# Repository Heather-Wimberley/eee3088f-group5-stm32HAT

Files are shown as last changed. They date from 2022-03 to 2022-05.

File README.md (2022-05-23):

# EEE088F Group 5

A HAT design to be added to the STM32 microcontroller.

## Proximity and Temperature Sensing HAT

Our HAT will include a temperature and proximity sensor. These sensors will allow for our HAT to provide the device it is attached to with useful parameters of its environment. The device we will be attaching our HAT to is the STM32 Discovery Microcontroller. The scenario we would use our HAT in would be to create efficient water dispensers. The proximity sensor will be able to detect when a bottle/hand is in position to receive water and the temperature sensor will help to monitor the water’s temperature. Other scenarios our HAT could be used in include drones, cars and automatic sliding doors

## Contents
This repo contains all files needed to understand the functionality of the HAT as well as have the HAT built. A description of the folder contents can be found below:

* [CAD](https://gitlab.com/wmbhea001/eee088f-group-5/-/tree/main/CAD) - Models and designs associated with the project

* [Docs](https://gitlab.com/wmbhea001/eee088f-group-5/-/tree/main/Docs) - Documentation which may include schematics, datasheets and manuals

* [Firmware](https://gitlab.com/wmbhea001/eee088f-group-5/-/tree/main/Firmware) - Source code for the HAT's software interface. 

* [PCB](https://gitlab.com/wmbhea001/eee088f-group-5/-/tree/main/PCB) - Contains PCB schematic diagrams 

* [Production](https://gitlab.com/wmbhea001/eee088f-group-5/-/tree/main/Production) - Documents relating to cost of HAT and production of HAT

* [Simulation](https://gitlab.com/wmbhea001/eee088f-group-5/-/tree/main/PCB/Simulation) - Contains documents neccessary for the fabrication of the HAT

## Get started with Proximity and Temperature HAT

### Introduction 
In the guide below, the process of how to set-up and run the Proximity and Temperature HAT will be described. The HAT is intended to be attached to and powered by a STM32 Discovery Board and powered by an 18650 battery when the STM is not connected to an external device via USB. It is able to store data in memory and in future versions provide this data to the USB-connected device.

### What you will need
Hardware:
- STM Discovery Board
- USB mini-B
- Female Pin-Headers (ver 1)
- Male-Female Wires (ver 1)
- USB micro-B
- 18650 Battery (optional)
- 18650 Battery Holder (optional)

Software:
- STM32CubeIDE

### Setup
1.	Plug the STM discovery board into the HAT with both USBs on the same side (pin headers and wires are used in the original version to account for the footprint issue as seen below).

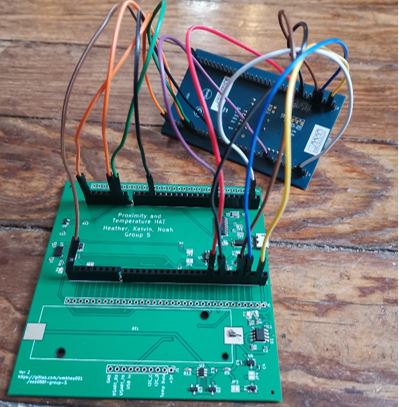
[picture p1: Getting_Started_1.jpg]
Getting_Started_1


*Figure 1: STM32F051 Discovery Board connected to Proximity and Temperature HAT (version 1 with wires)*

2.	Connect the HAT to a power source by either
- Clipping the 18650 battery holder to the connection shown below and place the battery in the holder (the lights on the discovery board should turn on)

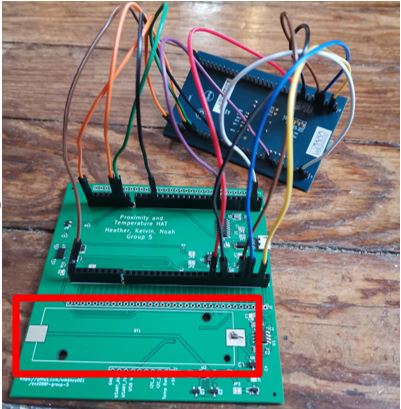
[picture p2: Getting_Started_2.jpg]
Getting_Started_2


*Figure 2: Location to plug in battery holder*

OR

- Plugging the HAT into a USB power source using the USB micro-B which will turn on the light D4

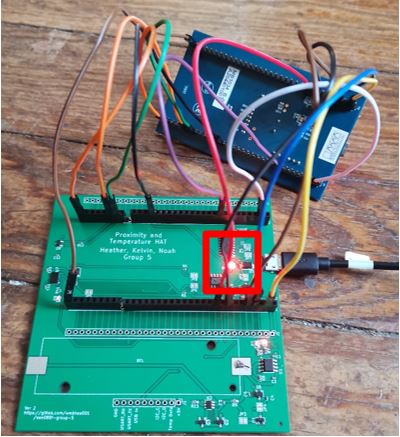
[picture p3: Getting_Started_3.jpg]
Getting_Started_3


*Figure 3: HAT powered by USB connection with USB detect light on*

3.	Plug the STM discovery board into your computer used for coding using the USB mini-B

4.	Open the firmwave files in the CubeIDE application. Add the following code to the main.c file in the section called int main(void). This serves as the main section to add code to interface with the HAT
 
```c
int main(void)
{
  Initialise(); //start all peripherals on the discovery board

  while (1)
  {
    uint32_t proximity, temp;//variables to store the proximity and temperature data
    uint8_t dataRead[32678];//array of all the data on the EEPROM
    get_sensor_data(&proximity, &temp);//measure the values at the sensors
    store_one_set(&temp, &proximity);//store the values on the EEPROM
    read_all_data(&dataRead);//read the EEPROM data into the variable 
  }
}
```

5.	Run a debug in the CubeIDE and add a watch to the dataRead variable. Stepping through the code will allow you to observe the changes in the EEPROM (future versions of the HAT will display this directly to an interface)

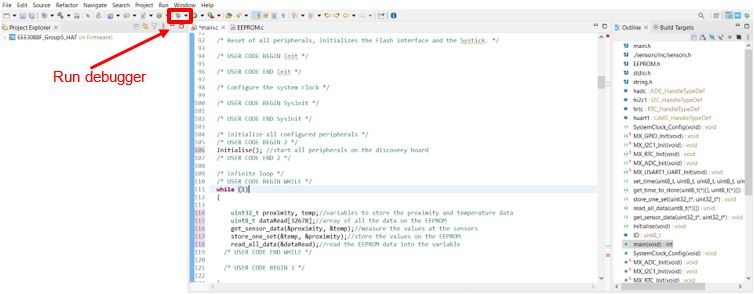
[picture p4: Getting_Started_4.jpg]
Getting_Started_4


*Figure 4: Run the debugger from the CubeIDE*

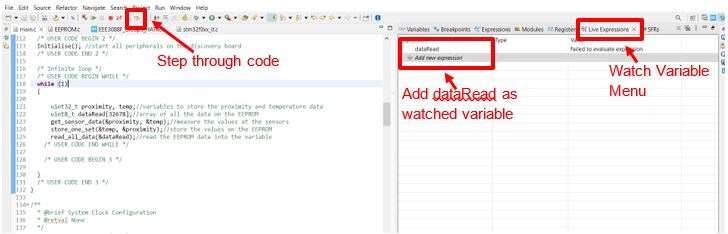
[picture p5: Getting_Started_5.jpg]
Getting_Started_5


*Figure 5: Add dataRead as a watched variable and step through the code*

Congratulations! You now have a HAT for your STM32 discovery board that can measure temperature and proximity.

## Support
Any questions concerning the project can be addressed to the project developers at wmbhea001@myuct.ac.za; ynkkel001@myuct.ac.za or; hvknoa001@myuct.ac.za

## Contributing
Please refer to [Contributing.md](https://gitlab.com/wmbhea001/eee088f-group-5/-/blob/main/CONTRIBUTING.md) for more information

## Authors and acknowledgment
Project designers are Kelvin Yankey, Heather Wimberley and Noah Havik.

## License
This project is bound by the Apache License 2.0

## Project status
Project is currently under development.

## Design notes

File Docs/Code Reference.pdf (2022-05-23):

Proximity and Temperature HAT | Group 5 | Software Documentation

# Proximity and Temperature HAT: Software Documentation

# Contents

# Overview

This document contains information on all the code that has been written and compiled as a companion to the proximity and temperature HAT that was designed. It also contains all files needed to run the HAT as intended.

# Files

### User Application Files

The basic software of the Proximity and Temperature HAT interfacing with the STM32f0 discovery board is comprised of the following files. This have been written or compiled by the engineering team.

File | Description
main.h/ .c | This file contains all of the functions written to allow a more user-friendly interface with the other files. It also initialises the STM32f0. User code can be written here to change the functioning of the board and microcontroller.
EEPROM.h/ .c | This file is a library written by controllerstech downloadable at https://github.com/controllerstech/STM32/tree/master/EEPROM_STM32.

| This library was used to simplify the user commands needed to read, write to the EEPROM and erase the EEPROM
prox.h/ .c | Contains definitions for functions used to control the proximity sensor
temp.h/ .c | Contains definitions for functions used to control the temperature sensor
types.h | Contains the definitions for types used throughout the API
sensors.h | Contains the public facing functions of the sensor api and is intended to be used by the end user

Table 1: User Application Files

### HAL files

The next files are HAL drivers needed to run the above code. The descriptions have been obtained from the HAL API documentation found at https://www.st.com/resource/en/user_manual/dm00105879-description-of-stm32f4-hal-and-ll-drivers-stmicroelectronics.pdf. (https://www.st.com/resource/en/user_manual/dm00105879-description-of-stm32f4-hal-and-ll-drivers-stmicroelectronics.pdf)

File | Description
stm32f0xx_hal_conf.h | This file allows the user to customize the HAL drivers for a specific application. It is not mandatory to modify this configuration. The application can use the default configuration without any modification.
stm32f0xx_it.h/ .c | This file contains the exceptions handler and peripherals interrupt service routine, and calls HAL_IncTick() at regular time intervals to increment a local variable (declared in stm32f4xx_hal.c) used as HAL timebase. By default, this function is called each 1ms in Systick ISR. The PPP_IRQHandler() routine must call HAL_PPP_IRQHandler() if an interrupt based process is used within the application.
stm32f0xx_hal_msp.c | This file contains the MSP initialization and de-initialization (main routine and callbacks) of the peripheral used in the user application.
system_stmf0xx.c | This file contains SystemInit() that is called at startup just after reset and before branching to the main program. It does not configure the system clock at startup (contrary to the standard library). This is to be done using the HAL APIs in the user files. It allows relocating the vector table in internal SRAM and configuring the FSMC/FMC (when available) to use the external SRAM or SDRAM mounted on the evaluation board as data memory.

Table 2: HAL Files

# Functions

### Main.c

SystemClock_Config
Function Name
void SystemClock_Config(void);

Function Description
Initializes the system clock for the STM32f0

Parameters
None

Return Values
None

MX_GPIO_Init
Function Name
static void MX_GPIO_Init(void);

Function Description
Initializes the GPIO for the STM32f0 including the pins for the USB detect (including the associated interrupt), Temperature active, Proximity active, Proximity Interrupt and discovery board LEDS.

Parameters
None

Return Values
None

MX_I2C1_Init
Function Name
static void MX_I2C1_Init(void);

Function Description
Initializes the I2C1 communication line for the STM32f0 using pins PB7 and PB8.

Parameters
None

Return Values
None

MX_RTC_Init
Function Name
static void MX_RTC_Init(void);

Function Description
Initializes the RTC (real time clock) onboard the STM32f0. Default time is 16:30:00 on 19/05/2022

Parameters
None

Return Values
None

MX_ADC_Init
Function Name
static void MX_ADC_Init(void);

Function Description
Initializes the ADC for the STM32f0 to receive data from the temperature sensor

Parameters
None

Return Values
None

set_time
Function Name
void set_time(uint8_t hour,uint8_t minute, uint8_t second, uint8_t Month, uint8_t Date, uint8_t Year);

Function Description
Sets the time of the real time clock to a user specified time

Parameters
Hour: user defined hour
minute: user defined minute
second: user defined second
Month: user defined month. Can use RTC definitions eg. RTC_MONTH_MAY
Date: user defined date
Year: user difined year. Needs to be less then 255 so store year-2000 and add the 2000 when displaying later

Return Values
None

get_time_to_store
Function Name
void get_time_to_store(uint8_t (*time)[3],uint8_t (*date)[3]);

Function Description
Retrives the current time and date from the RTC and stores it in 2 arrays of length 3 and size one byte. One array has time and the other has the date

Parameters
time: pointer to user defined array of 3 variables that will store current time
date: pointer to user defined array of 3 variables that will store current time

Return Values
None

store_one_set
Function Name
void store_one_set(uint32_t *temp, uint32_t *proximity);

Function Description
Stores one set of data in the EEPROM which includes the ID of that set, the temperature data, proximity data and the time from the RTC.

Parameters
temp: pointer to user defined uint32 containing the temperature
proximity: pointer to user defined uint32 containing the proximity

Return Values
None

read_all_data
Function Name
void read_all_data (uint8_t (*dataRead)[32678]);

Function Description
Reads all of the data currently stored on the EEPROM and stores it in an array

Parameters
dataRead: pointer to user defined array that will store the EEPROM data

Return Values
None

get_sensor_data
Function Name
void get_sensor_data (uint32_t *proximity,uint32_t *temp);

Function Description
Stores the data currently received from the 2 sensors in user defined variables

Parameters
proximity: pointer to user defined byte to contain proximity
temp: pointer to user defined byte to contain proximity

Return Values
None

get_sensor_data
Function Name
void Intialise(void);

Function Description
Initialises all of the STM32 functions as well as starting the sensors. It contains all previously mentioned initialisation functions

Parameters
None

Return Values
None

HAL_GPIO_EXTI_Callback
Function Name
void HAL_GPIO_EXTI_Callback(uint16_t GPIO_Pin);

Function Description
Defines the action taken of the USB detect interrupt

Parameters
GPIO_Pin: Pin connected to the interrupt

Return Values
None

Global Variables
uint8_t ID – stores the current value of the ID that is used to store values in the EEPROM

### EEPROM.c

All of the following references and information have been copied from the original library

EEPROM_Write
Function Name
void EEPROM_Write (uint16_t page, uint16_t offset, uint8_t *data, uint16_t size)

Function Description
write the data to the EEPROM

Parameters
page: the number of the start page. Range from 0 to PAGE_NUM-1 offset: the start byte offset in the page. Range from 0 to PAGE_SIZE-1 data: the pointer to the data to write in bytes
size: the size of the data

Return Values
None

EEPROM_Write_NUM
Function Name
void EEPROM_Write_NUM (uint16_t page, uint16_t offset, float data)

Function Description
Write the Float/Integer values to the EEPROM

Parameters
page: the number of the start page. Range from 0 to PAGE_NUM-1 offset: the start byte offset in the page. Range from 0 to PAGE_SIZE-1 data: the float/integer value that you want to write

Return Values
None

EEPROM_Read_NUM
Function Name
float EEPROM_Read_NUM (uint16_t page, uint16_t offset)

Function Description
Reads the single Float/Integer values from the EEPROM

Parameters
page: the number of the start page. Range from 0 to PAGE_NUM-1 offset: the start byte offset in the page. Range from 0 to PAGE_SIZE-1

Return Values
the float/integer value

EEPROM_Read
Function Name
void EEPROM_Read (uint16_t page, uint16_t offset, uint8_t *data, uint16_t size)

Function Description
READ the data from the EEPROM

Parameters
page: the number of the start page. Range from 0 to PAGE_NUM-1 offset: the start byte offset in the page. Range from 0 to PAGE_SIZE-1 data: the pointer to the data to write in bytes
size: the size of the data

Return Values
None

EEPROM_PageErase
Function Name
float EEPROM_Read_NUM (uint16_t page, uint16_t offset)

Function Description
Erase a page in the EEPROM Memory. In order to erase multiple pages, just use this function in the for loop

Parameters
page: the number of the pages to erase

Return Values
None

### Sensors.h

The following list of functions comprise the public facing functions of the sensor api and is intended to be used by the end user

Sensors_Start
Function Name
SensorErrorType Sensors_Start(ADC_HandleTypeDef *hadc, I2C_HandleTypeDef* i2cHandler)

Function Description
Initialize the Sensors to start the data collection process
Parameters
- hadc - the handler of the adc configured by the user. Instructions about specific ports can be found in the readme
- i2cHandler - the handler of the i2c configuration defined by the user.

Return Values
SensorErrorType – Indicating the result of the operation

Sensors_Stop
Function Name
SensorErrorType Sensors_Stop(void) Function Description
Places both sensors in a standby state Parameters
N/A

Return Values
SensorErrorType – Indicating the result of the operation

Sensors_GetMeasurement
Function Name
SensorErrorType Sensors_GetMeasurement(struct SensorData *out, int maxTime) Function Description
Obtains all measurements and stores it in a pointer to sensor data

Parameters
- out - a pointer to the struct{SensorData} in which the results from measurements will be stored. End user is responsible for creating and managing the struct
- maxTime – the maximum time the operation should take, if this time is exceeded, the function will abort with an error

Return Values
SensorErrorType – Indicating the result of the operation

### Types.h

Contains the definitions for types used throughout the API

SensorData
Definition
struct SensorData {
float temp;
int32_t prox;
};

Description
This struct will hold a result from a polling measurement operation.

SensorErrorType
Definition
typedef enum SensorErrorType;

Description
An enum holding the result from various operations in the api. Below are the enum fields as well as their descriptions
- OK – The function was successful
- PROX_CALIBRATION_ERROR – The proximity sensor could not calibrate itself and thus could not start
- PROX_INIT_ERROR – The proximity sensor could not start
- PROX_MEASURE_ERROR – There was an error while getting a measurement
- PROX_NOT_RESPONDING – The proximity sensor did not respond when prompted for a result

The following section describes private definitions which should not be used by the end user

### Prox.h

Contains definitions for functions used to control the proximity sensor

ProximitySensor_Start
Function Name
SensorErrorType ProximitySensor_Start(I2C_HandleTypeDef* i2cHandler) Function Description
Starts the proximity sensor
Parameters
- i2cHandler - the handler of the i2c configuration defined by the user.

Return Values
SensorErrorType – Indicating the result of the operation

EnsureHandlersValid
Function Name
void EnsureHandlersValid(void)
Function Description
Internal function to ensure that the various handlers the api uses are still valid

Parameters
N/A

Return Values
N/A

ProximitySensor_GetSingleShotMeasurement
Function Name
SensorErrorType ProximitySensor_GetSingleShotMeasurement(int32_t* result) Function Description
Gets a distance measurement once at a time

Parameters
- result - A pointer to the integer variable holding the result of the operation in millimetres

Return Values
SensorErrorType – Indicating the result of the operation

ProximitySensor_Stop
Function Name
SensorErrorType ProximitySensor_Stop(void) Function Description
Places the proximity sensor in standby mode

Parameters
N/A

Return Values
SensorErrorType – Indicating the result of the operation

ProximitySensor_IsReady
Function Name
SensorErrorType ProximitySensor_IsReady(void) Function Description
Checks whether the proximity sensor is ready and responding

Parameters
N/A

Return Values
SensorErrorType – Indicating the result of the operation

Interrupt based functions for use if required

ProximitySensor_Start_IT
Function Name
SensorErrorType ProximitySensor_Start_IT(I2C_HandleTypeDef* i2cHandler, int freq) Function Description
Starts the proximity sensor in interrupt mode. User is responsible for setting up the GPIO interrupt in hardware

Parameters
- i2cHandler - the handler of the i2c configuration defined by the user.
- Freq – The frequency at which interrupts will occur

Return Values
SensorErrorType – Indicating the result of the operation

ProximitySensor_OnInterruptStarted
Function Name
SensorErrorType ProximitySensor_OnInterruptStarted(void) Function Description
Function to be called once the interrupt detection has been set up

Parameters
N/A

Return Values
SensorErrorType – Indicating the result of the operation

ProximitySensor_OnInterruptDetected
Function Name
SensorErrorType ProximitySensor_OnInterruptDetected(int32_t* result) Function Description
Called when the interrupt fires. Will output the measurement results

Parameters
- result - A pointer to the integer variable holding the result of the operation in millimetres

Return Values
SensorErrorType – Indicating the result of the operation

### Temp.h

Contains definitions for functions used to control the temperature sensor

TempSensor_Start
Function Name
SensorErrorType TempSensor_Start(ADC_HandleTypeDef *hadc) Function Description
Starts the temperature sensor

Parameters
- hadc - the handler of the adc configured by the user. Instructions about specific ports can be found in the readme

Return Values
SensorErrorType – Indicating the result of the operation

TempSensor_GetMeasurement
Function Name
SensorErrorType TempSensor_GetMeasurement(int maxTime, float* result) Function Description
Get the current measurement from the temperature sensor

Parameters
- result - is a pointer to a double which will hold the result
- maxTime - is the maximum amount of time you can wait before a result needs to be returned. Can be dictated by the sampling rate
Return Values
SensorErrorType – Indicating the result of the operation

TempSensor_HasStarted
Function Name
SensorErrorType TempSensor_HasStarted(void) Function Description
Checks if the temperature has started

Parameters
N/A

Return Values
SensorErrorType – Indicating the result of the operation

TempSensor_Stop
Function Name
SensorErrorType TempSensor_Stop(void) Function Description
Stop the temperature sensor

Parameters
N/A

Return Values
SensorErrorType – Indicating the result of the operation

The following files are part of source code taken from the VL6180 Api and thus, documentation can be found at the STMicroelectronics website

- vl6180_api.h/ .c
- vl6180_cfg.h
- vl6180_def.h

- vl6180_i2c.h/ .c
- vl6180_platform.h/ .c

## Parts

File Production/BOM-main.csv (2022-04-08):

Comment | Designator | Footprint | LCSC
CH340G | U3 | SOIC-16_3.9x9.9mm_P1.27mm | C14267
AO3401A | Q1 | SOT-23 | C15127
10nF | C7 | C_0402_1005Metric | C15195
100nF | C3,C9 | C_0402_1005Metric | C1525
4.7nF | C11 | C_0402_1005Metric | C1538
10uF | C1,C2 | C_0402_1005Metric | C15525
33pF | C6,C8 | C_0402_1005Metric | C1562
TP4056 | U1 | ESOP-8_L4.9-W3.9-P1.27-LS6.0-BL-EP | C16581
1k | R13,R3,R7 | R_0603_1608Metric | C21190
1.2k | R8 | R_0603_1608Metric | C22765
100 | R1,R9 | R_0603_1608Metric | C22775
RLED | D4,D6,D9 | LED_0603_1608Metric | C2286
YLED | D2 | LED_0805_2012Metric | C2296
150 | R4 | R_0402_1005Metric | C25082
330 | R10,R12 | R_0402_1005Metric | C25104
10k | R11,R5,R6 | R_0402_1005Metric | C25744
VL6180XV0NR_1 | U7 | LGA-12_L4.8-W2.8-P0.75-BL | C2655167
BZT52C3V0 | D8 | D_SOD-123 | C266562
100nF | C10 | C_0402_1005Metric | C307331
USB_Micro_B | U4 | C404969_Micro_USB | C404969
BAT54S | D1 | D_SOT-23_ANK | C408389
MCP9700T-ETT | U8 | SOT-23 | C42288
0.4 | R2 | R_0805_2012Metric | C52548
1uF | C12,C4,C5 | C_0402_1005Metric | C52923
XC6206P332MR | U6 | SOT-23 | C5446
AT24C256C-SSHL-T | U5 | SOIC-8_L4.9-W3.9-P1.27-LS6.0-BL | C6482
ZMM5V1-M | D3 | LL-34_L3.5-W1.5-RD | C8061
FS312F-G | U2 | SOT-23-6 | C82736
2N7002 | Q2,Q3 | SOT-23 | C8545
12MHz Crystal | X1 | OSC-SMD_4P-L3.2-W2.5-BL | C9002
DIODE | D5 | DO-214AC_L4.3-W2.7-LS5.3-RD | C95872

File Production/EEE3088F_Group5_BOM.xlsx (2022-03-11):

Source: | D:\UCT 2022\EEE3088F Design Principles\Task\Git\eee088f-group-5\PCB\main\main.kicad_sch
Date: |  | 2022-03-11 18:34
Tool: | Eeschema (6.0.2)
Item | Qty | Reference(s) | Value | LibPart | JLC Part # | Price ($) | Total for components | Total Cost
1 | 1 | BT1 | 5V | 18650 | - | - | -
2 | 2 | C1,C6 | 0.1uF | Device:C | C1525 | 0.0011 | 0.0022 | 7.7399
3 | 1 | C2 | 22uF | Device:C | C59461 | 0.0098 | 0.0098
4 | 1 | C3 | 300pF | Device:C | C1534 | 0.0017 | 0.0017
5 | 2 | C4, C5 | 33p | Device:C | C1562 | 0.0012 | 0.0024
7 | 1 | C7 | 100n | Device:C_Polarized | C307331 | 0.0065 | 0.0065
8 | 1 | C8 | 4.7n | Device:C_Polarized | C1538 | 0.0011 | 0.0011
9 | 2 | D1, D2 | 30V 1V@100mA 200mA | BAT54S | C408389 | 0.0148 | 0.0296
10 | 1 | D3 | 1A 5μA@1kV 1kV 1.1V@1A | 1N4007 | C106903 | 0.0189 | 0.0189
11 | 1 | D4 | 2μA@1V 85Ω Single 3.1V~3.5V 500mW 3.3V | ZMM3V3-M | C8056 | 0.0188 | 0.0188
13 | 1 | D6 | 100nA@1V 35Ω Single 4.8V~5.4V 500mW 5.1V | ZMM5V1-M | C8061 | 0.0182 | 0.0182
14 | 4 | D5, D7, D9, D10 | LED | Device:LED | C2286 | 0.0032 | 0.0128
15 | 1 | D8 | BZT52C3V0 | Diode:BZT52Bxx | C266562 | 0.0136 | 0.0136
16 | 2 | J1, J4 | Conn_01x33_Female | Connector:Conn_01x33_Female
17 | 2 | J2, J3 | Conn_01x33_Female | Connector:Conn_01x33_Female
18 | 1 | J5 | Conn_01x03_Female | Connector:Conn_01x03_Female
19 | 6 | JP1, JP2, JP3, JP4, JP5, JP6 | SolderJumper_2_Bridged | Jumper:SolderJumper_2_Bridged
20 | 6 | JP7, JP8, JP9, JP10, JP11, JP12 | SolderJumper_2_Bridged | Jumper:SolderJumper_2_Bridged
21 | 2 | M1 | 20V 2.3A 350mW 112mΩ@4.5V,2.8A 1V@250μA | CJ2301 | C8547 | 0.0447 | 0.0894
22 | 2 | Q1 | FDS6690A | Symbol_EEE3088F:FDS6690A | C87667 | 0.7380 | 1.476
23 | 1 | R 1 | 2M | Device:R | C25744 | 0.0007 | 0.0007
24 | 1 | R 2 | 806K | Device:R | C375495 | 0.0007 | 0.0007
25 | 1 | R 3 | 130 | Device:R | C25744 | 0.0007 | 0.0007
26 | 1 | R 4 | 27 | Device:R | C25190 | 0.0013 | 0.0013
27 | 2 | R 5 | 1M | Device:R | C26083 | 0.0007 | 0.0014
28 | 1 | R 6 | 1k | Device:R | C11702 | 0.0008 | 0.0008
29 | 1 | R 7 | 12 | Device:R | C880162 | 0.0111 | 0.0111
30 | 1 | R 8 | 82 | Device:R | C23255 | 0.0014 | 0.0014
31 | 4 | R9, R10, R13, R16 | 10k | Device:R | C25744 | 0.0007 | 0.0028
32 | 3 | R11, R12, R14 | 330 | Device:R | C25104 | 0.0007 | 0.0021
34 | 1 | R 15 | 220 | Device:R | C25091 | 0.0007 | 0.0007
35 | 1 | RV1 | 50K | Device:R_Potentiometer | C145161 | 0.0860 | 0.086
36 | 1 | U1 | 100mA 600mV@(100mA) Fixed 3.3V~3.3V Positive 1 30V | LP2951-33DR | C109381 | 0.5769 | 0.5769
37 | 1 | U2 | LM324 | 0.4 V/us 4 1.3MHz 3V ~ 32V, ±1.5V ~ 16V 1.5mA | C71035 | 0.1561 | 0.1561
38 | 1 | U3 | CH340G | Interface_USB:CH340G | C14267 | 0.5856 | 0.5856
39 | 1 | U4 | USB_Micro_B | Symbol_EEE3088F:USB_Micro_B_Female_Connector | C319160 | 0.0673 | 0.0673
40 | 1 | U5 | AT24C256C-SSHL-T | Symbol_EEE3088F:AT24C256C-SSHL-T | C6482 | 1.5556 | 1.5556
41 | 1 | U6 | VL6180XV0NR_1 | EEE3088Components:VL6180XV0NR_1 | C2655167 | 2.1412 | 2.1412
42 | 1 | U7 | MCP9700T-ETT | Sensor_Temperature:MCP9700T-ETT | C42288 | 0.7397 | 0.7397
43 | 1 | X1 | 12MHz Crystal | Symbol_EEE3088F:12MHz_SMD_Crystal | C9002 | 0.1054 | 0.1054
44 | 1 | R15 | 47k | Device:R | C25792 | 0.0007 | 0.0007
45 | 1 | R16 | 150k | Device:R | C25755 | 0.0007 | 0.0007
 |  |  |  |  |  |  | 7.7385

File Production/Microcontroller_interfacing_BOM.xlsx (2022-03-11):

Option No | Type | Part | JLCPCB Part # | Cost | Basic/Extended
USB Interfacing
1 | USB serial interface | Transceiver 2Mbps USB 2.0 SOP-16_150mil USB ICs ROHS | C14267 | $0.6029 | E
2 | FTDI | LQFP-48_7x7x05P USB ICs ROHS | C51997 (https://lcsc.com/product-detail/USB-ICs_FTDI-FT232HL-REEL_C51997.html) | $4.8695 | E
3 | FTDI (alt) | Transceiver 12Mbps USB 2.0 LQFP-48_7x7x05P USB ICs ROHS | C111668 | $2.718 | E
4 | FTDI (alt) | Transceiver 1Mbps USB 1/1 QFN-28_5x5x05P USB ICs ROHS | C6568 | $3.7227 | B
USB Connector
1 | USB Micro B | USB 2.0 1 5 Female Micro-B SMD USB Connectors ROHS | C319160 | $0.0673 | E
2 | USB Micro B (alt) | 1A USB 2.0 1 5 Female Micro-B SMD USB Connectors ROHS | C10418 | $0.0749 | E
EEPROM
1 | EEPROM | 1.7V ~ 5.5V I2C 256Kb (32K x 8) SOIC-8_150mil EEPROM ROHS | C6482 | $1.6371 | B
Crystal
1 | 12Mhz Crystal | 12MHz SMD Crystal Resonator 20pF ±10ppm ±30ppm -40℃~+85℃ SMD3225-4P Crystals ROHS | C9002 | $0.1054 | B
Total anticipated |  |  |  | ±$2.4127
 |  |  |  | Above is using first option
 | Not accounted for are resistors, capacitors and diodes which are cheap
 |  |  |  |  |  | Quantity
 | Red LED | Red 615~630nm 1.9~2.2V 0603 Light Emitting Diodes (LED) RoHS | C2286 | $0.0032 | B | 1
 | 75 ohm | ±1% 1/10W Thick Film Resistors 75V ±100ppm/℃ -55℃~+155℃ 82Ω 0603 Chip Resistor - Surface Mount ROHS | C23255 | $0.0014 | B | 1
 | 10k ohm | ±1% 1/16W Thick Film Resistors 50V ±100ppm/℃ -55℃~+155℃ 10kΩ 0402 Chip Resistor - Surface Mount ROHS | C25744 | $0.0007 | B | 2
 | 33pF | 50V 33pF C0G ±5% 0402 Multilayer Ceramic Capacitors MLCC - SMD/SMT ROHS | C1562 | $0.0012 | B | 2
 | 0.1uF | 16V 100nF X7R ±10% 0402 Multilayer Ceramic Capacitors MLCC - SMD/SMT ROHS | C1525 | $0.0011 | B | 1

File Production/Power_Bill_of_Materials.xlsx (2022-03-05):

Part | JLC PCB | Cost
100mA 600mV@(100mA) Fixed 3.3V~3.3V Positive 1 30V SOIC-8_150mil Linear Voltage Regulators (LDO) ROHS | C109381 | $0,53
50V 130MA 225MW 10Ω@5V,100MA 2V@250ΜA P CHANNEL SOT-23(SOT-23-3) MOSFETS ROHS | LBSS84LT1G | $0,03
0.6 V/US 2 1MHZ 3V ~ 32V, ±1.5V ~ 16V 1.5MA GENERAL PURPOSE SOIC-8_150MIL OPERATIONAL AMPLIFIER ROHS | LM358DR2G | $0.14
 | Total | ± $0.70
Resistors, capacitors and diodes not included as they are cheap, basic parts

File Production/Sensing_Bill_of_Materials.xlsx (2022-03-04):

Name | Reference | Part Number | JLC Part Number | Datasheet | Value | Cost | Quantity | Subtotal
Temperature Sensor | U1 | MCP9700T-E/TT | C42288 | https://datasheet.lcsc.com/lcsc/1809192127_Microchip-Tech-MCP9700T-E-TT_C42288.pdf | N/A | 0.8315 | 1 | 0.8315
Capacitor | C1 |  |  |  | 100n | 0 | 1 | 0
Capacitor | C2 | N/A | N/A | N/A | 4.7n | 0 | 1 | 0
 | D1 |  |  |  |  | 0 | 1 | 0
 | D2 |  |  |  |  | 0 | 1 | 0
 | D3 |  |  |  |  | 0 |  | 0
BJT Transistor | Q1 | N/A | N/A | N/A | N/A | 0 | 1 | 0
 | R1 |  |  |  |  | 0 | 1 | 0
 | R2 |  |  |  |  | 0 | 1 | 0
 | R3 |  |  |  |  | 0 | 1 | 0
 | R4 |  |  |  |  | 0 | 1 | 0
 | R5 |  |  |  |  | 0 | 1 | 0
 | R6 |  |  |  |  | 0 | 1 | 0
Proximity Sensor | U2 | VL6180XV0NR_1 | C2655167 | https://datasheet.lcsc.com/lcsc/2106080034_STMicroelectronics-VL6180V1NR-1_C2655167.pdf | N/A | 2.23 | 1 | 2.23
 |  |  |  |  |  |  |  | Total
 |  |  |  |  |  |  |  | 3.0615

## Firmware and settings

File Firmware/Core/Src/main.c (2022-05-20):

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
/* Includes ------------------------------------------------------------------*/
#include "main.h"

/* USER CODE BEGIN Includes */
#include "./sensors/inc/sensors.h"
#include "EEPROM.h"
#include <stdio.h>
#include "string.h"
/* USER CODE END Includes */

ADC_HandleTypeDef hadc;

I2C_HandleTypeDef hi2c1;

RTC_HandleTypeDef hrtc;

void SystemClock_Config(void);
static void MX_GPIO_Init(void);
static void MX_I2C1_Init(void);
static void MX_RTC_Init(void);
static void MX_ADC_Init(void);
/* USER CODE BEGIN PFP */
void set_time(uint8_t hour,uint8_t minute, uint8_t second, uint8_t Month, uint8_t Date, uint8_t Year);
void get_time_to_store(uint8_t (*time)[3],uint8_t (*date)[3]);
void store_one_set(uint32_t *temp, uint32_t *proximity);
void read_all_data (uint8_t (*dataRead)[32678]);
void get_sensor_data (uint32_t *proximity,uint32_t *temp);
void Initialise(void);
/* USER CODE END PFP */

/* USER CODE BEGIN 0 */
uint8_t ID = 1;
/* USER CODE END 0 */

/**
  * @brief  The application entry point.
  * @retval int
  */
int main(void)
{

	Initialise();
  /* USER CODE END 2 */

  /* Infinite loop */
  /* USER CODE BEGIN WHILE */
  while (1)
  {
	  uint32_t proximity, temp;
	  uint8_t dataRead[32678];
	  get_sensor_data(&proximity, &temp);
	  store_one_set(&temp, &proximity);
	  read_all_data(&dataRead);
    /* USER CODE END WHILE */

    /* USER CODE BEGIN 3 */

  }
  /* USER CODE END 3 */
}

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
/* USER CODE BEGIN 4 */
void Initialise(void)
{
	  HAL_Init();

	  SystemClock_Config();
	  MX_GPIO_Init();
	  MX_I2C1_Init();
	  MX_RTC_Init();
	  MX_ADC_Init();
	  Sensors_Start(&hadc, &hi2c1);

	  for (int i = 0; i<512;i++)
	  {
		  EEPROM_PageErase(i);
	  }
}

void get_sensor_data(uint32_t *proximity,uint32_t *temp)
{
	 struct SensorData data;
	 SensorErrorType result = Sensors_GetMeasurement(&data, 1);
	 *proximity = data.prox;
	 *temp = data.temp;

}

void read_all_data (uint8_t (*dataRead)[32678])
{
	EEPROM_Read(1, 0, *dataRead, 32768);
}

void set_time (uint8_t hour,uint8_t minute, uint8_t second, uint8_t Month, uint8_t Date, uint8_t Year)
{
  RTC_TimeTypeDef sTime;
  RTC_DateTypeDef sDate;
  sTime.Hours = hour;
	sTime.Minutes = minute;
	sTime.Seconds = second;
	sTime.DayLightSaving = RTC_DAYLIGHTSAVING_NONE;
	sTime.StoreOperation = RTC_STOREOPERATION_RESET;
	if (HAL_RTC_SetTime(&hrtc, &sTime, RTC_FORMAT_BCD) != HAL_OK)
	{
		Error_Handler();
	}
	sDate.WeekDay = RTC_WEEKDAY_FRIDAY;
	sDate.Month = Month;
	sDate.Date = Date;
	sDate.Year = Year;

	if (HAL_RTC_SetDate(&hrtc, &sDate, RTC_FORMAT_BCD) != HAL_OK)
	{
		Error_Handler();
	}
  HAL_RTCEx_BKUPWrite(&hrtc, RTC_BKP_DR1, 0x32F2); // backup register
}

void get_time_to_store(uint8_t (*time)[3],uint8_t (*date)[3])
{
	 RTC_DateTypeDef gDate;
	 RTC_TimeTypeDef gTime;
	/* Get the RTC current Time */
	 HAL_RTC_GetTime(&hrtc, &gTime, RTC_FORMAT_BIN);
	/* Get the RTC current Date */
	 HAL_RTC_GetDate(&hrtc, &gDate, RTC_FORMAT_BIN);
	/* Display time Format: hh:mm:ss */
	 *time[0] = gTime.Hours;
	 *time[1] = gTime.Minutes;
	 *time[2] = gTime.Seconds;
	/* Display date Format: dd-mm-yy */
	 *date[0] = gDate.Date;
	 *date[1] = gDate.Month;
	 *date[2] = gDate.Year;
}

void store_one_set(uint32_t *temp, uint32_t *proximity)
{
	uint8_t time[3], date[3];
	get_time_to_store(&time, &date);
	if(ID<1024)
	{
		uint8_t datas[16];
		datas[0] = ID;
		memcpy(datas + 1, &temp, sizeof(uint32_t));
		memcpy(datas + 5, &proximity, sizeof(uint32_t));
		memcpy(datas + 9, time, 3 * sizeof(uint8_t));
		memcpy(datas + 12, date, 3 * sizeof(uint8_t));
		uint8_t pages = (ID-1)/4+1;
		uint16_t sizes = 16;
		uint16_t offsets = (ID-1)%4*16;

		EEPROM_Write (pages, offsets , datas ,sizes);
		ID++;
	}
}


void HAL_GPIO_EXTI_Callback(uint16_t GPIO_Pin)
{
    if ( GPIO_Pin == USB_on_Pin)
    {
    	HAL_GPIO_WritePin(GPIOC, GPIO_PIN_8, GPIO_PIN_SET);
    }
}
/* USER CODE END 4 */
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


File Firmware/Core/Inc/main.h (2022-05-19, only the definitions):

#define B1_Pin GPIO_PIN_0
#define B1_GPIO_Port GPIOA
#define USB_on_Pin GPIO_PIN_4
#define USB_on_GPIO_Port GPIOA
#define USB_on_EXTI_IRQn EXTI4_15_IRQn
#define Temp_Active_Pin GPIO_PIN_0
#define Temp_Active_GPIO_Port GPIOB
#define Temp_Data_Pin GPIO_PIN_1
#define Temp_Data_GPIO_Port GPIOB
#define LD4_Pin GPIO_PIN_8
#define LD4_GPIO_Port GPIOC
#define LD3_Pin GPIO_PIN_9
#define LD3_GPIO_Port GPIOC
#define SWDIO_Pin GPIO_PIN_13
#define SWDIO_GPIO_Port GPIOA
#define SWCLK_Pin GPIO_PIN_14
#define SWCLK_GPIO_Port GPIOA
#define Proximity_Active_Pin GPIO_PIN_4
#define Proximity_Active_GPIO_Port GPIOB
#define Proximity_Interrupt_Pin GPIO_PIN_5
#define Proximity_Interrupt_GPIO_Port GPIOB

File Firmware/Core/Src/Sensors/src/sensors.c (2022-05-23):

/*
 * sensors.c
 *
 *  Created on: May 10, 2022
 *      Author: kelvi
 */

#include "../inc/sensors.h"

char SensorMode = 0;

/* @description
 * Initialize the Sensors to start collecting data
 *
 * @arguments
 * @hadc is the handler of the adc configured by the user. Instructions about specific
 * ports can be found in the readme
 * @i2cHandler is the handler of the i2c configuration defined by the user.
 * @returns SensorErrorType
 *
 *
 * */

SensorErrorType Sensors_Start(ADC_HandleTypeDef *hadc, I2C_HandleTypeDef* i2cHandler){
	if (SensorMode != 0 || SensorMode != 1){
		// Sensor configured in interrupt mode
		return SENSOR_INIT_ERROR;
	}
	SensorErrorType result = ProximitySensor_Start(i2cHandler);
	if (result != OK){
		return result;
	}
	result = TempSensor_Start(hadc);
	if (result != OK){
			return result;
	}
	return OK;

}

/* @description
 *
 * Places both sensors in a stand by state
 * @arguments
 * @returns SensorErrorType
 */
SensorErrorType Sensors_Stop(void){
	SensorErrorType result = ProximitySensor_Stop();
	if (result != OK){
		return result;
	}
	return TempSensor_Stop();
}
/*
 * @description
 * This will get all measurements and store it in a pointer to sensor data struct
 *
 * @arguments
 * @{SensorData} out - a pointer to the struct in which the results from measurements will be stored
 * @{int} maxTime - the maximum time the sensors should take to get information, if the time is exceeded, the function will return an error
 *
 *
 *
 */


SensorErrorType Sensors_GetMeasurement(struct SensorData *out, int maxTime){
	if (TempSensor_HasStarted() != 1){
		return 1;
	}
	if (ProximitySensor_IsReady() != OK){
		return 1;
	}
	float temp = 0;
    SensorErrorType result = TempSensor_GetMeasurement(1, &temp);
    if (result != OK){
    	return result;
    }
    int32_t prox = 0;


	out->temp = temp;
	result = ProximitySensor_GetSingleShotMeasurement(&prox);
	out->prox = prox;
	return result;
}


SensorErrorType Sensors_Start_IT(ADC_HandleTypeDef *hadc, I2C_HandleTypeDef* i2cHandler, int freq){
	if (SensorMode != 0 || SensorMode != 2){
		// Sensor configured in polling mode
		return SENSOR_INIT_ERROR;
	}
	SensorErrorType result = ProximitySensor_Start_IT(i2cHandler, freq);
	if (result != OK){
		return result;
	}
	result = TempSensor_Start(hadc);
	if (result != OK){
			return result;
	}
	SensorMode = 2;
	return OK;


}

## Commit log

2022-03-03 Upload Microcontroller interfacing Bill of Materials
    [Microcontroller_interfacing_BOM.xlsx]
2022-03-03 Update Microcontroller_interfacing_BOM.xlsx to include other small components
    [Microcontroller_interfacing_BOM.xlsx]
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2022-03-04 Added Sensing Bill of Materials
    [Sensing_Bill_of_Materials.xlsx]
2022-03-04 Upload Power_Bill_of_Materials
    [Power_Bill_of_Materials.xlsx]
2022-03-05 Replace Power_Bill_of_Materials.xlsx
    [Power_Bill_of_Materials.xlsx]
2022-03-08 Add schematic files
    [main.kicad_pcb, main.kicad_sch, microcontroller_interfacing.kicad_sch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]
2022-03-08 Upload draft microcontroller_interfacing.kicad_sch
    [microcontroller_interfacing.kicad_sch]
2022-03-08 Change labels to global labels
    [main.kicad_pcb, main.kicad_sch, microcontroller_interfacing.kicad_sch]
2022-03-08 Added Kicad Libraries
    [main.kicad_sch, microcontroller_interfacing.kicad_sch]
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2022-03-08 Add Kicad footprints and symbols
    [main.kicad_sch, microcontroller_interfacing.kicad_sch]
2022-03-09 Add more footprints and files
    [main.kicad_pcb]
2022-03-09 update schematics
    [Microcontroller_interfacing_BOM.xlsx, main.kicad_sch, microcontroller_interfacing.kicad_sch]
2022-03-09 Update Schematic
    [Microcontroller_interfacing_BOM.xlsx, PCB_NEW_PCB_2022-03-09 (4).kicad_pcb]
2022-03-10 Update Schematic and BOM
    [Microcontroller_interfacing_BOM.xlsx, main.kicad_sch, microcontroller_interfacing.kicad_sch]
2022-03-10 Update Schematic with jumpers
    [main.kicad_sch, microcontroller_interfacing.kicad_sch]
2022-03-10 Add notes
    [main.kicad_sch, microcontroller_interfacing.kicad_sch, outputs.kicad_sch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]
2022-03-10 Correct jumpers and add headers
    [main.kicad_sch, microcontroller_interfacing.kicad_sch]
2022-03-11 Add datasheets and update schematic
    [main.kicad_sch, microcontroller_interfacing.kicad_sch]
2022-03-11 Neaten schematic
    [main.kicad_sch, microcontroller_interfacing.kicad_sch]
2022-03-11 power save
    [main.kicad_sch, power.kicad_sch]
2022-03-11 Update paths
    [main.kicad_sch, microcontroller_interfacing.kicad_sch]
2022-03-11 Change ports
    [main.kicad_sch, microcontroller_interfacing.kicad_sch]
2022-03-11 add footprint
    [main.kicad_sch, microcontroller_interfacing.kicad_sch]
2022-03-11 Added Sensing Schematics
    [main.kicad_sch, power.kicad_sch, sensing.kicad_sch]
2022-03-11 add pins
    [Proximity_Sensor.kicad_sch, main.kicad_sch, microcontroller_interfacing.kicad_sch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]
2022-03-11 Fixed Missing Schematics
    [Proximity_Sensor.kicad_sch, main.kicad_sch, temperature_sensor.kicad_sch]
2022-03-11 Add sheet properties
    [Proximity_Sensor.kicad_sch, main.kicad_sch, power.kicad_sch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]
2022-03-11 Add changes
    [Proximity_Sensor.kicad_sch, main.kicad_sch, microcontroller_interfacing.kicad_sch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]
2022-03-11 Add usb sensing
    [Proximity_Sensor.kicad_sch, main.kicad_sch, microcontroller_interfacing.kicad_sch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]
2022-03-11 Add comments
    [Proximity_Sensor.kicad_sch, main.kicad_sch, microcontroller_interfacing.kicad_sch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]
2022-03-11 final changes
    [main.kicad_sch, power.kicad_sch]
2022-03-11 Add Bill Of Materials
    [EEE3088F_Group5_BOM.xlsx]
2022-03-11 Add labels
    [main.kicad_sch, power.kicad_sch]
2022-03-13 Fixed incorrect connection for MOSFET in Sensing Subsystem \n\n Since the BJT switch has been replaced by a MOSFET switch, the Should Stop pin in the temperature sensor should become an Active pin. I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
    [sensing.kicad_sch, temperature_sensor.kicad_sch]
2022-03-14 Correct labels
    [Proximity_Sensor.kicad_sch, main.kicad_sch, microcontroller_interfacing.kicad_sch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]
2022-03-14 Work on reducing ERC flags
    [Proximity_Sensor.kicad_sch, main.kicad_sch, microcontroller_interfacing.kicad_sch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]
2022-03-14 Add footprints
    [Proximity_Sensor.kicad_sch, main.kicad_sch, microcontroller_interfacing.kicad_sch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]
2022-03-16 Connect pins to ground
    [microcontroller_interfacing.kicad_sch]
2022-03-16 Add power flags
    [Proximity_Sensor.kicad_sch, main.kicad_sch, temperature_sensor.kicad_sch]
2022-03-16 Add USB footprint
    [Proximity_Sensor.kicad_sch, main.kicad_sch, microcontroller_interfacing.kicad_sch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]
2022-03-16 circuit edits
    [main.kicad_sch, power.kicad_sch]
2022-03-17 Small changes
    [Proximity_Sensor.kicad_sch, main.kicad_sch, power.kicad_sch]
2022-03-17 Change labels
    [main.kicad_sch, power.kicad_sch]
2022-03-17 Add voltage regulator
    [main.kicad_sch, microcontroller_interfacing.kicad_sch, power.kicad_sch]
2022-03-17 add hierachal sheet
    [Cutout_protection.kicad_sch, main.kicad_sch, power.kicad_sch]
2022-03-17 Updated BOM
    [Proximity_Sensor.kicad_sch, Regulation and Step Down.kicad_sch, USBPolarityProtection.kicad_sch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]
2022-03-17 pmosfet name
    [Cutout_protection.kicad_sch, main.kicad_sch, power.kicad_sch]
2022-03-17 Add footprints and test points
    [Cutout_protection.kicad_sch, main.kicad_sch, microcontroller_interfacing.kicad_sch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]
2022-03-18 Correct op-amp symbol
    [Cutout_protection.kicad_sch]
2022-03-18 Design PCB
    [Cutout_protection.kicad_sch, Proximity_Sensor.kicad_sch, main.kicad_pcb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]
2022-03-18 Fix DRC errors
    [main.kicad_pcb, main.kicad_sch]
2022-03-18 Change names
    [Cutout_protection.kicad_sch, main.kicad_sch, microcontroller_interfacing.kicad_sch]
2022-03-18 Replace EEE3088F_Group5_BOM.xlsx
    [EEE3088F_Group5_BOM.xlsx]
2022-03-18 Add header
    [Cutout_protection.kicad_sch, Proximity_Sensor.kicad_sch, main.kicad_pcb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]
2022-03-19 Added QR Code.
    Cleaned up PCB project structure. Just moved contents in main out to the root folder
    Added to git ignore for autosave files
    [Cutout_protection.kicad_sch, Proximity_Sensor.kicad_sch, Regulation and Step Down.kicad_sch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]
2022-03-19 Labelled Test Points
    [Cutout_protection.kicad_sch, main.kicad_pcb, main.kicad_sch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]
2022-03-19 Fixed tp labels
    [main.kicad_pcb]
2022-03-19 Fixed QR Code
    [main.kicad_pcb]
2022-03-20 Improve folder layout
    [Cutout_protection.kicad_sch, Proximity_Sensor.kicad_sch, main.kicad_pcb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]
2022-03-20 Revert "Improve folder layout"
    This reverts commit b367b5c65dac769aee4b1abf86922fcf3d684084
    [Cutout_protection.kicad_sch, Proximity_Sensor.kicad_sch, main.kicad_pcb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]
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2022-03-20 Revert "again"
    This reverts commit 3983b3a2bbd3cb989ba3f9e8c32b60b336cbf8a7
    [Cutout_protection.kicad_sch, EEE3088F_Group5_BOM.xlsx, Proximity_Sensor.kicad_sch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]
2022-03-20 Revert "pcb n"
    This reverts commit 8727529f109f5bdd44d95993405a88df4b4ab9b1
    [main.kicad_pcb]
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2022-03-20 Fix pcb file
    [main.kicad_pcb]
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2022-03-22 Correct layout
    [main-B_Cu.gbr, main-B_Mask.gbr, main-B_Paste.gbr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]
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2022-04-03 Mostly addressed issues with Sensing subsystem
    [Cutout_protection.kicad_sch, Proximity_Sensor.kicad_sch, main.kicad_sch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]
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2022-04-04 Fix JLCPCB plugin
    [BOM-main.csv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]
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2022-04-06 Revert "NEW CHARGER"
    This reverts commit f70cef7c904ac9a65cb3dc731ad4395f14296498
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2022-04-08 Fix rotation
    [POS-main.csv]
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2022-05-10 Added Proximity code
    Reorganised folders to avoid refactoring everything
    Basic sensor API finished
    Need to investigate interrupt operation
    [main.c, prox.c, sensors.c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]
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

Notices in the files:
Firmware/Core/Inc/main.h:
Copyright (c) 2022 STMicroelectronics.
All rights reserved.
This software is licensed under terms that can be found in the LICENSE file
